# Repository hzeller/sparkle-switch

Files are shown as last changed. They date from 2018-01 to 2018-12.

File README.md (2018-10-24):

Sparkleswitch
=============

The Noisebridge Laser cutter is an expensive piece of machinery that has
some non-negligible running cost and requires some safety-training before use.

We require to authenticate with an RFID showing previous laser training
in order to switch the laser on. This project contains the relevant electronics
and software to build this switch.

We use a generic EStop/On/Off switch box ([Aliexpress][switch-box-ali], [Amazon][switch-box-amazon]) as basic user interface, coupled with an
additional [RFID reader].

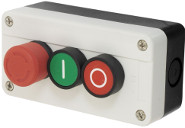
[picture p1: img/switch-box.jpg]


## Requirements

 * Have a switch that provides on/off and emergency off buttons as well
   as an RFID reader.
 * The safety relevant triggering of the emergency button **must**
   shut off power reliably by simple electromechanical means with no software
   involved to work even if the computer has issues.
   After an Emergency-Off, it is required to reset the EStop button
   (manual twisting) _and_ re-activating via RFID.
 * Have a display to show the currently active user, potentially laser
   time accounting, uplifting idle-animations etc.
 * It is common to pass the custody of the running laser cutter to the next
   user, so make it simple to switch the active user without power-cycling
   the laser.
 * Connection between Pi and emergency off button is separate, so it should
   be simple to wire up.

## Design considerations

As controlling computer, we use a Raspberry Pi: it is cheap, [can run
a LED display][rpi-rgb-matrix], and has enough additional GPIO pins to
read button state and trigger relays.

Since we need to switch line voltage with the Pi, we use a relay.
The basic switch mechanism is a simple relay circuit acting as a Set/Reset
Flip-Flop that fails safe on power loss.
Two control relays for set/reset are triggered by the Raspberry Pi; the main
switching 4-pole relay is part of the flip-flop and also switching the
mains phases for the machine.

The mains relay uses one of its poles to act as self-sustaining relay.
A momentary switch of the 'on' trigger relay will switch on the machine,
and a momentary interrupt from the 'off' trigger will switch off the machine:

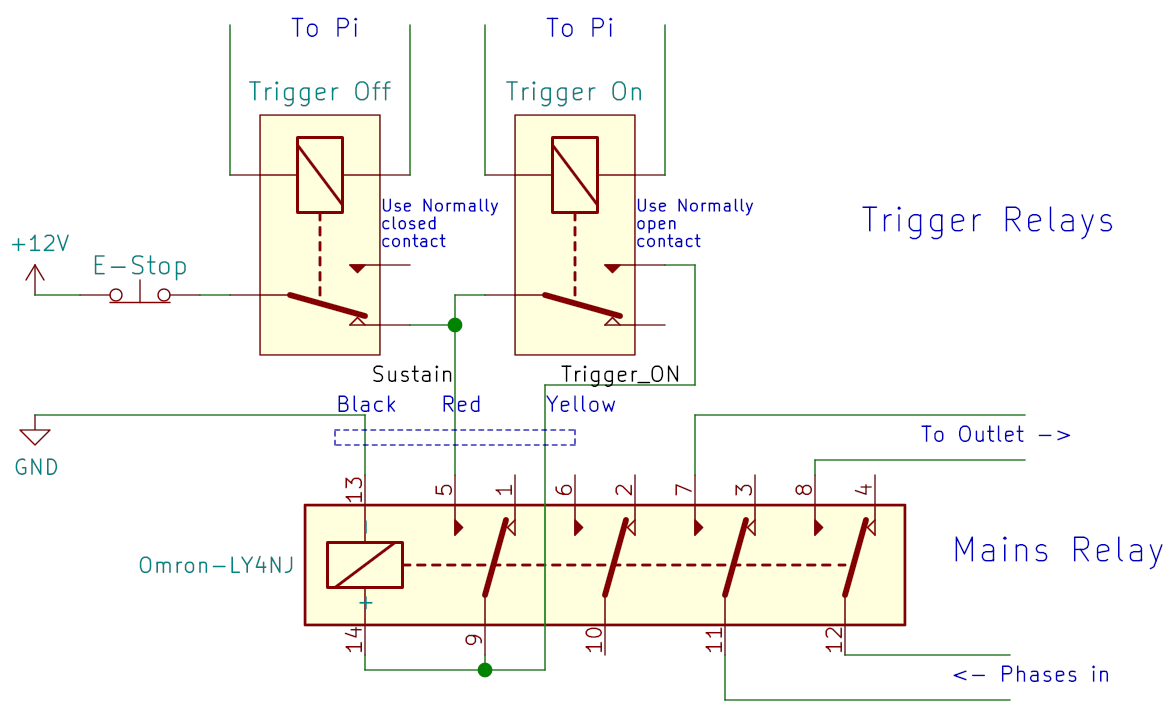
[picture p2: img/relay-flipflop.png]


The Emergency-Off button is cutting power to the relay circuit, thus acting
as master reset (thereby meeting the no-software-involved safety requirements).
Set (= switch power on) and Reset (= switch power off) are triggered by the
Raspberry Pi.

Inputs and outputs are

 * `in` **Emergency Off** button. Directly wired in the
    circuit acting as physical 'reset' for the SR-FlipFlop. Also wired to a
    GPIO as input to inform the application about the state.
 * `in` **On** button. Wired to a GPIO input as a soft-button for
    the application.
 * `in` **Off** button. Wired to a GPIO input as a soft-button for the
    application.
 * `in` a sense input to detect if the mains-relay coil voltage is on. Mostly
    for fault detection via software.
 * `out` **Trigger on** relay. Controlled by GPIO
    to trigger *set* of SR-FlipFlop.
 * `out` **Trigger off** relay. Controlled by GPIO
    to trigger *reset* of SR-FlipFlop.
 * `serial in/out` **RFID** reader (connected to UART on Pi).

Since we use the on/off buttons to interact with the application as
soft-buttons (e.g. to trigger 'pending off'), they are not physically wired
into the circuit but used as input to the computer (this is fine as they
are not in the safety critical path).

There is a little space in the switch box which will house the trigger relays
and possibly the RFID reader. The relay switching of the line voltage for the
laser cutter is mounted near the outlet for the machine, connected with three
wires (see above:`GND`, `Sustain`, `Trigger ON`) remotely from the switch box.

As trigger relays, we use off-the-shelf and [cheap][ebay-search-dual-relay]
relays.

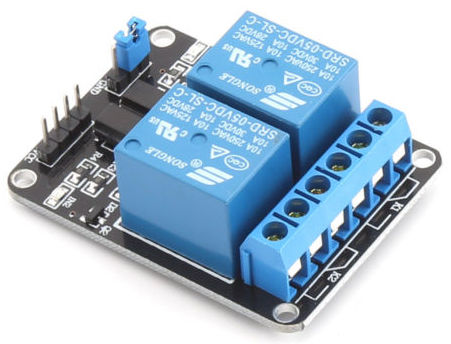
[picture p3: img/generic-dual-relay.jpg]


## State machine

The software on the Pi implements the following state machine; it uses inputs
and outputs mentioned above.
Inputs are on the transition edges; external actions triggered by the
application are represented as hexagons. Since we often have the situation
that we want to pass the running laser to the next user without having to
switch it entirely off and on again, there is a provision to change the user
while the machine is running:

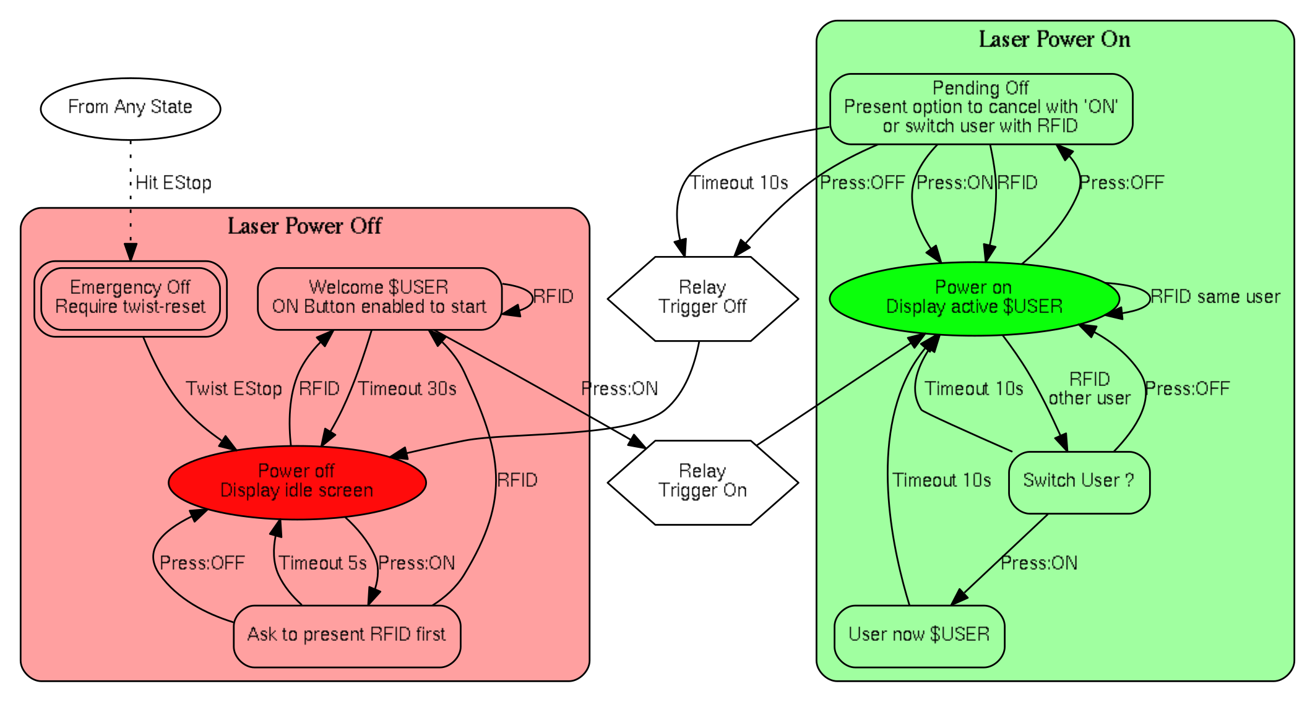
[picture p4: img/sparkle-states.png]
Sparkleswitch states


## Components

There are three physical parts to the system:

  1. RGB LED matrix screen, that has a Raspberry Pi connected to it to
     display the user interface.
  2. The switch box is separate from that and mounted under the display.
  3. The mains relay that is close to the outlet of the
     laser-cutter, and remotely controlled with a 12V control voltage.

The connection between the switch-box and the Pi is a simple flat cable with
an [IDC-12 connector] on both ends.

| Desc | Pin | Pin | Desc
|---:|:---:|:---:|:---
| +5V  | 1 | 2 | +5V (low current; for trigger relays and RFID)
| Sense EStop `in` | 3 | 4 | `in` sense relay voltage (e.g. for failure detection)
| Off-Button `in` | 5 | 6 | `out` Relay Trigger Off
| On-Button `in` | 7 | 8 | `out` Relay Trigger On
| GND  | 9 |  10 | GND
| UART RX on Pi  |  11 |  12 | UART TX on Pi (3.3V TTL)

There is a PCB on the Raspberry Pi to wire up the LED panels and provide the
connector to the switch-box, and a PCB in the switch-box as a breakout board.

### Pi Sparkle HAT

The Rasbperry Pi connects to the [Pi Sparkle HAT](./hardware/pi-hat), that
provides connections for two chains of HUB75 RGB LED matrix
(using the [rpi-rgb-matrix] project) and the
Sparkleswitch-specific IDC-12 connector to connect to the switch box.

Inputs (from switches and sense-lines all operating at 12V) are insulated with
opto couplers. The relay trigger outputs are 5V TTL
(but non-insulated as the receiving end uses opto-couplers already).

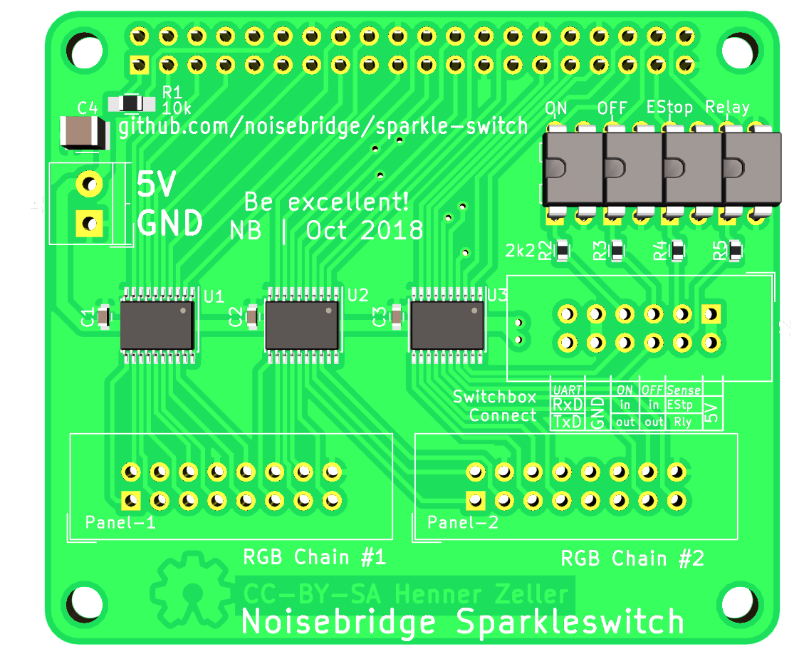
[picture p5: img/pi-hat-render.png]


### Switch Box

A [small breakout board in the switch-box](./hardware/switch-connector)
provides a way to connect the switches, the Trigger-Relays (housed inside the
switch-box) and the RFID reader (attached to switch box). It also provides a
screw terminal to wire up to the mains-relay whose wires are also terminating
in the switch box.

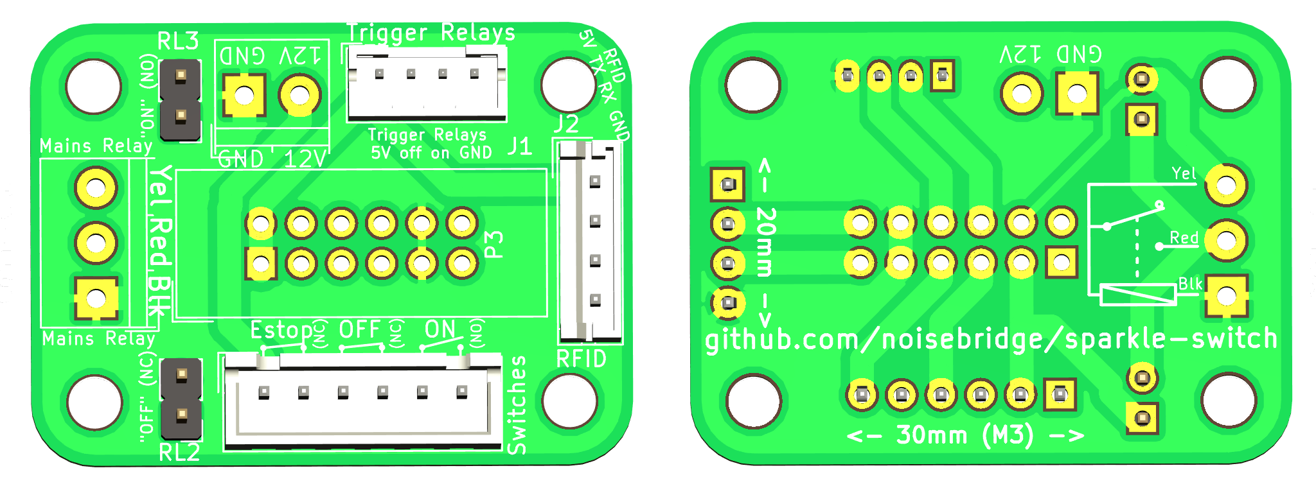
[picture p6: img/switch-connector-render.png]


[switch-box-ali]: https://www.aliexpress.com/wholesale?SearchText=NC+Emergency+Stop+Red+Green
[switch-box-amazon]: https://www.amazon.com/gp/product/B0097B4YK0
[rpi-rgb-matrix]: https://github.com/hzeller/rpi-rgb-led-matrix
[RFID reader]: https://github.com/noisebridge/rfid-access-control/tree/master/hardware/terminal
[IDC-12 Connector]: https://www.google.com/images?q=idc-12+connector
[ebay-search-dual-relay]: https://www.ebay.com/sch/i.html?_nkw=%222+channel%22+relay+arduino&_sop=15

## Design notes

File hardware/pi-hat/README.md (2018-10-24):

Pi Sparkle HAT
==============

The Sparkle HAT connects to Raspberry Pi GPIOs, does 3.3V->5V level shifting
to connect to HUB75 LED matrixes (to be controlled with the [rpi-rgb-matrix]
code), and the Sparkleswitch-specific IDC-12 connector to connect to the
switch box.

The level shifters are needed as the LED matrixes need 5V logic level. We also
use two free drivers to provide 5V TTL level for the trigger relay outputs
on the IDC-12 connector.

Inputs (from switches and sense-lines all operating at 12V) are insulated with
PC817 opto couplers. The relay trigger outputs are non-insulated as the
receiving end uses opto-couplers already.

To provide strong mechanical support, the HAT is full size with all four
mounting holes.

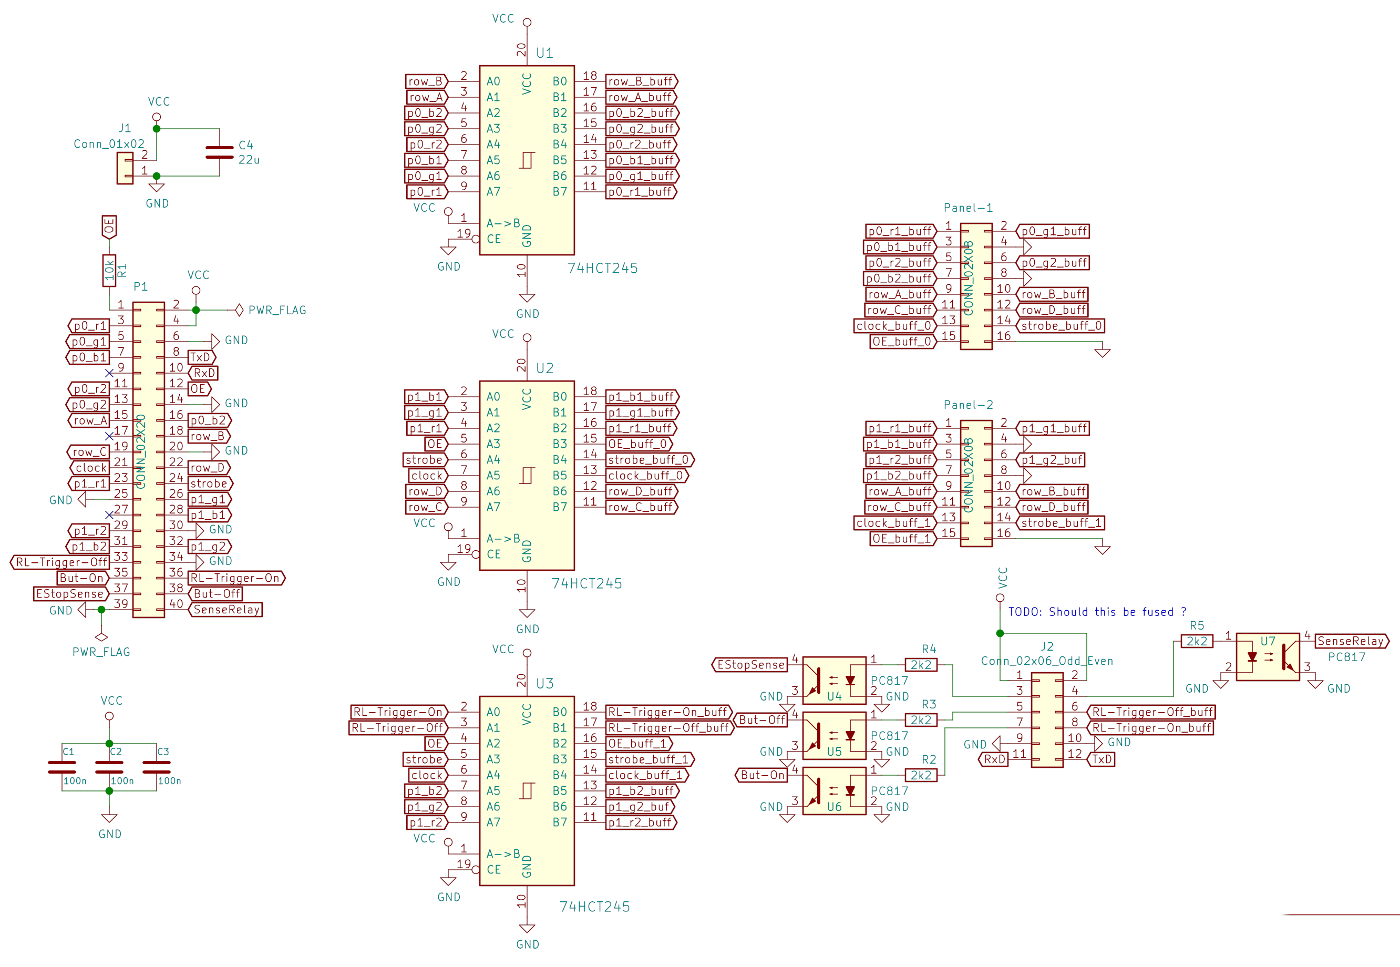
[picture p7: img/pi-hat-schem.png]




[rpi-rgb-matrix]: https://github.com/hzeller/rpi-rgb-led-matrix

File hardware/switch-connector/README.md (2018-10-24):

Switch Connector
================

The IDC-12 cable from the Raspberry Pi terminates inside the switch box.



There, it needs to connect to

   * The RFID reader via the serial interface.
   * Switches to sense which buttons are pressed (sent to Pi).
   * EStop button that is wired up as physical master-reset of the
     relay Set/Reset flip-flop. Also its state is sensed and sent to
     Pi to detect that condition in software.
   * Trigger relay inputs, controlled from the Pi.
   * The trigger relay switches, that are part of the Set/Reset flip-flop
   * And finally: the wires to the large mains relay.

To simplify that and improve maintainability, this is a small PCB inside the
switch box that provides the necessary connectors.

The IDC-12 connector has the following pinout:

| Desc | Pin | Pin | Desc
|---:|:---:|:---:|:---
| +5V  | 1 | 2 | +5V (low current; for trigger relays and RFID)
| Sense EStop `in` | 3 | 4 | `in` sense relay voltage (e.g. for failure detection)
| Off-Button `in` | 5 | 6 | `out` Relay Trigger Off
| On-Button `in` | 7 | 8 | `out` Relay Trigger On
| GND  | 9 |  10 | GND
| UART RX on Pi  |  11 |  12 | UART TX on Pi (3.3V TTL)

The connector to the On/Off/EStop switches is a 6 pos JST-XH connector,
which can be cheaply acquired pre-crimped, as they are also used as
battery charge balance connectors.

The connectors to the [RFID reader], and the input to the trigger relay are
also JST connectors. The former uses JST-XH (2.5mm pitch), the latter
JST-PH (2mm pitch) to avoid wrong wirings.

As trigger relay, simple generic dual relays are used, that are super-cheap
[on ebay][ebay-search-dual-relay]



## Schematic and Board

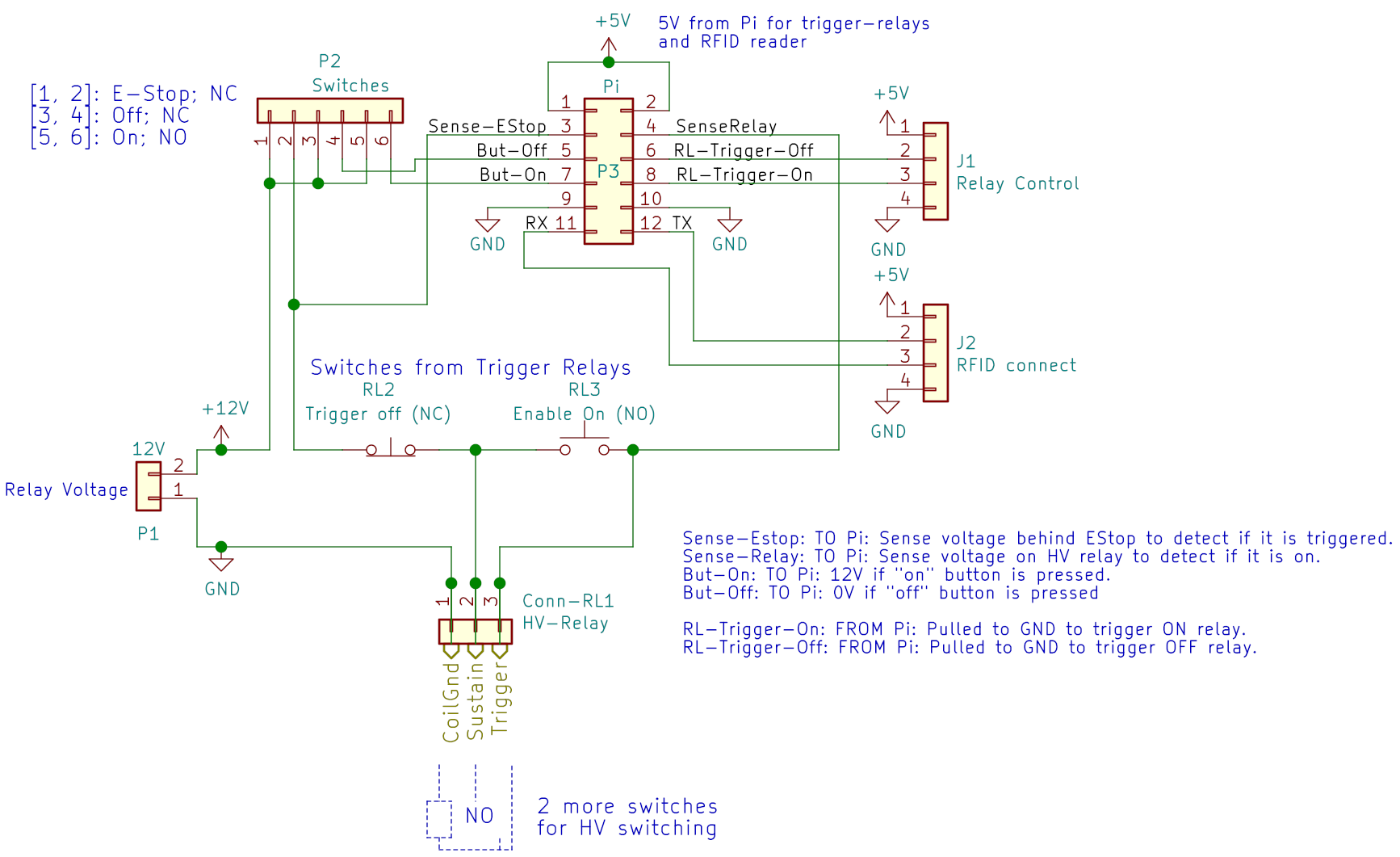
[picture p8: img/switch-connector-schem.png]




[RFID Reader]: https://github.com/noisebridge/rfid-access-control/tree/master/hardware/terminal
[ebay-search-dual-relay]: https://www.ebay.com/sch/i.html?_nkw=%222+channel%22+relay+arduino&_sop=15

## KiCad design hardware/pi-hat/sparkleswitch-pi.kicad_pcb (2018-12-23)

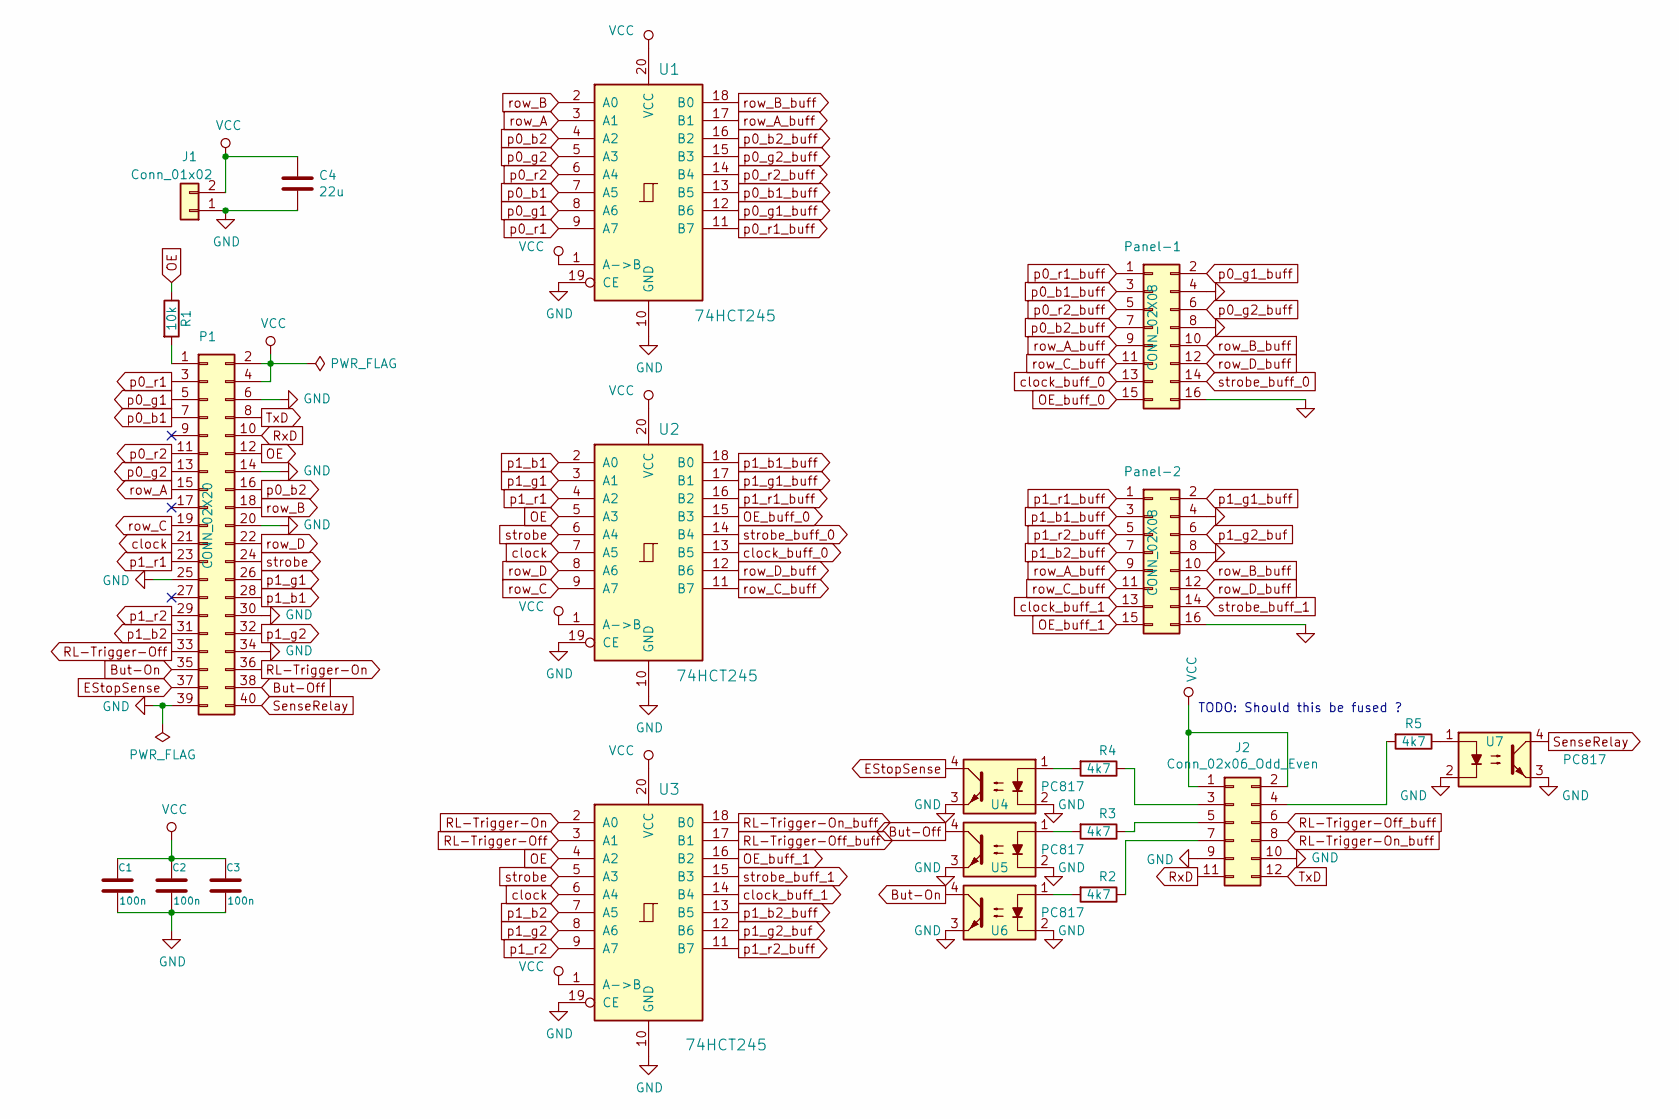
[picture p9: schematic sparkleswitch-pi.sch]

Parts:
C1, C2, C3: 100n; C_0603
C4: 22u; C_1210
J1: Conn_01x02; TerminalBlock_4UCON_19963_02x3.5mm_Straight
J2: Conn_02x06_Odd_Even; IDC-Header_2x06_Pitch2.54mm_Straight
P1: CONN_02X20; Socket_Strip_Straight_2x20_Pitch2.54mm
Panel-1, Panel-2: CONN_02X08; IDC-Header_2x08_Pitch2.54mm_Straight
R1: 10k; R_0603
R2, R3, R4, R5: 4k7; R_0603
U1, U2, U3: 74HCT245; SSOP-20_4.4x6.5mm_Pitch0.65mm
U4, U5, U6, U7: PC817; DIP-4_W7.62mm

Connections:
But-Off: P1.38, U5.4
But-On: P1.35, U6.4
EStopSense: P1.37, U4.4
GND: C1.2, C2.2, C3.2, C4.2, J1.1, J2.9, J2.10, P1.6, P1.14, P1.20, P1.25, P1.30, P1.34, P1.39, Panel-1.4, Panel-1.8, Panel-1.16, Panel-2.4, Panel-2.8, Panel-2.16, U1.10 (GND), U1.19 (CE), U2.10 (GND), U2.19 (CE), U3.10 (GND), U3.19 (CE), U4.2, U4.3, U5.2, U5.3, U6.2, U6.3, U7.2, U7.3
unnamed: J2.3, R4.1
unnamed: J2.4, R5.2
unnamed: J2.5, R3.1
unnamed: J2.7, R2.1
unnamed: P1.1, R1.2
unnamed: R2.2, U6.1
unnamed: R3.2, U5.1
unnamed: R4.2, U4.1
unnamed: R5.1, U7.1
OE: P1.12, R1.1, U2.5 (A3), U3.4 (A2)
OE_buff_0: Panel-1.15, U2.15 (B3)
OE_buff_1: Panel-2.15, U3.16 (B2)
RL-Trigger-Off: P1.33, U3.3 (A1)
RL-Trigger-Off_buff: J2.6, U3.17 (B1)
RL-Trigger-On: P1.36, U3.2 (A0)
RL-Trigger-On_buff: J2.8, U3.18 (B0)
RxD: J2.11, P1.10
SenseRelay: P1.40, U7.4
TxD: J2.12, P1.8
VCC: C1.1, C2.1, C3.1, C4.1, J1.2, J2.1, J2.2, P1.2, P1.4, U1.1 (A->B), U1.20 (VCC), U2.1 (A->B), U2.20 (VCC), U3.1 (A->B), U3.20 (VCC)
clock: P1.21, U2.7 (A5), U3.6 (A4)
clock_buff_0: Panel-1.13, U2.13 (B5)
clock_buff_1: Panel-2.13, U3.14 (B4)
p0_b1: P1.7, U1.7 (A5)
p0_b1_buff: Panel-1.3, U1.13 (B5)
p0_b2: P1.16, U1.4 (A2)
p0_b2_buff: Panel-1.7, U1.16 (B2)
p0_g1: P1.5, U1.8 (A6)
p0_g1_buff: Panel-1.2, U1.12 (B6)
p0_g2: P1.13, U1.5 (A3)
p0_g2_buff: Panel-1.6, U1.15 (B3)
p0_r1: P1.3, U1.9 (A7)
p0_r1_buff: Panel-1.1, U1.11 (B7)
p0_r2: P1.11, U1.6 (A4)
p0_r2_buff: Panel-1.5, U1.14 (B4)
p1_b1: P1.28, U2.2 (A0)
p1_b1_buff: Panel-2.3, U2.18 (B0)
p1_b2: P1.31, U3.7 (A5)
p1_b2_buff: Panel-2.7, U3.13 (B5)
p1_g1: P1.26, U2.3 (A1)
p1_g1_buff: Panel-2.2, U2.17 (B1)
p1_g2: P1.32, U3.8 (A6)
p1_g2_buf: Panel-2.6, U3.12 (B6)
p1_r1: P1.23, U2.4 (A2)
p1_r1_buff: Panel-2.1, U2.16 (B2)
p1_r2: P1.29, U3.9 (A7)
p1_r2_buff: Panel-2.5, U3.11 (B7)
row_A: P1.15, U1.3 (A1)
row_A_buff: Panel-1.9, Panel-2.9, U1.17 (B1)
row_B: P1.18, U1.2 (A0)
row_B_buff: Panel-1.10, Panel-2.10, U1.18 (B0)
row_C: P1.19, U2.9 (A7)
row_C_buff: Panel-1.11, Panel-2.11, U2.11 (B7)
row_D: P1.22, U2.8 (A6)
row_D_buff: Panel-1.12, Panel-2.12, U2.12 (B6)
strobe: P1.24, U2.6 (A4), U3.5 (A3)
strobe_buff_0: Panel-1.14, U2.14 (B4)
strobe_buff_1: Panel-2.14, U3.15 (B3)

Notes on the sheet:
TODO: Should this be fused ?

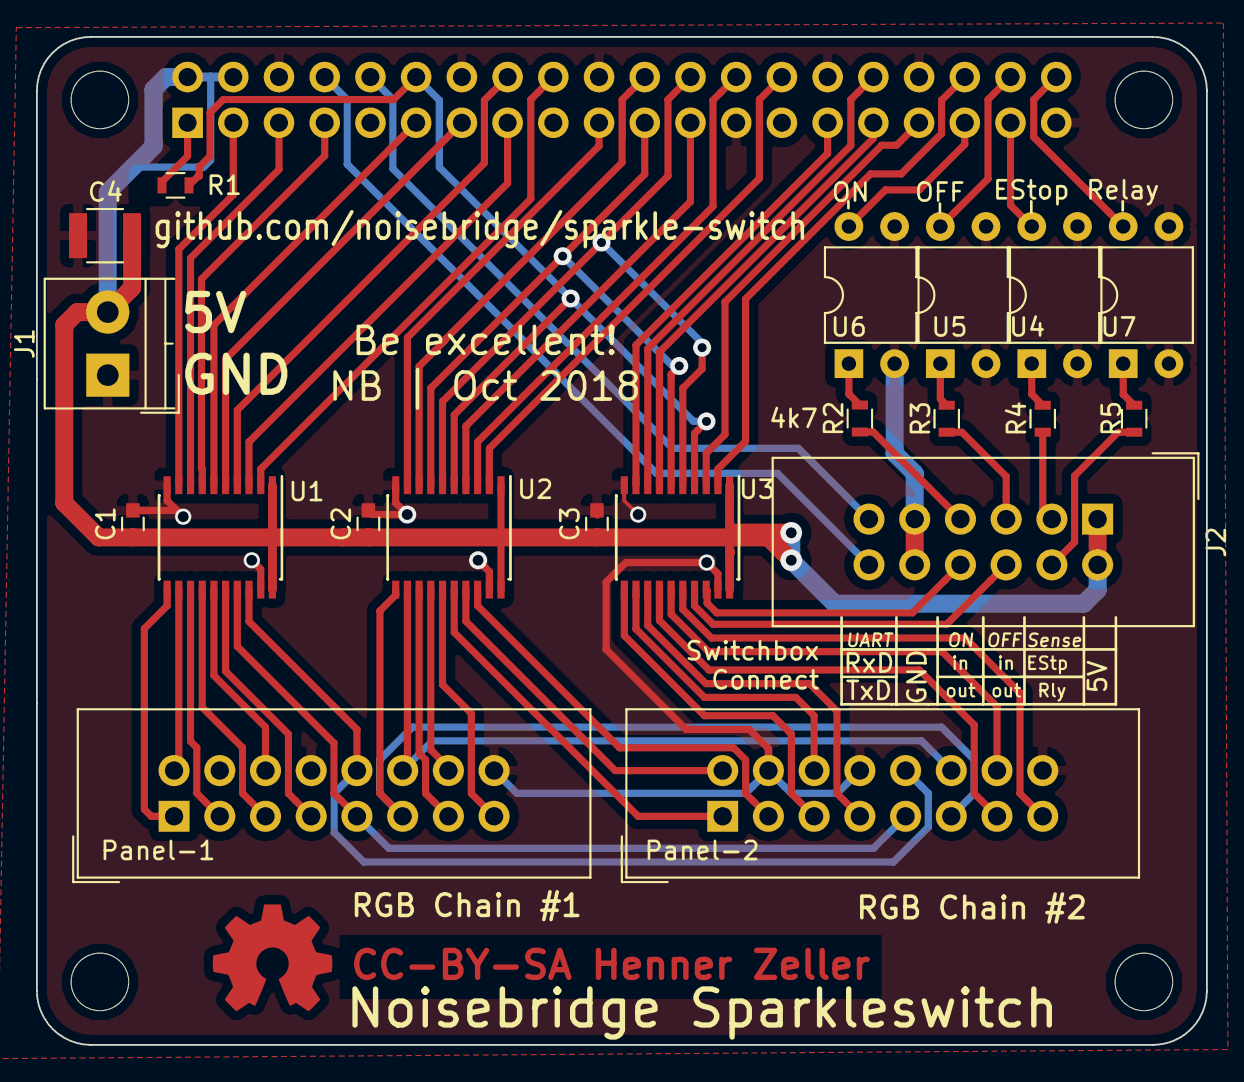
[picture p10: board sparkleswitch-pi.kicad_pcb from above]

Board: 2 copper layers, 65.0 x 56.0 mm, 21 parts (1 on the bottom side), 62 nets.

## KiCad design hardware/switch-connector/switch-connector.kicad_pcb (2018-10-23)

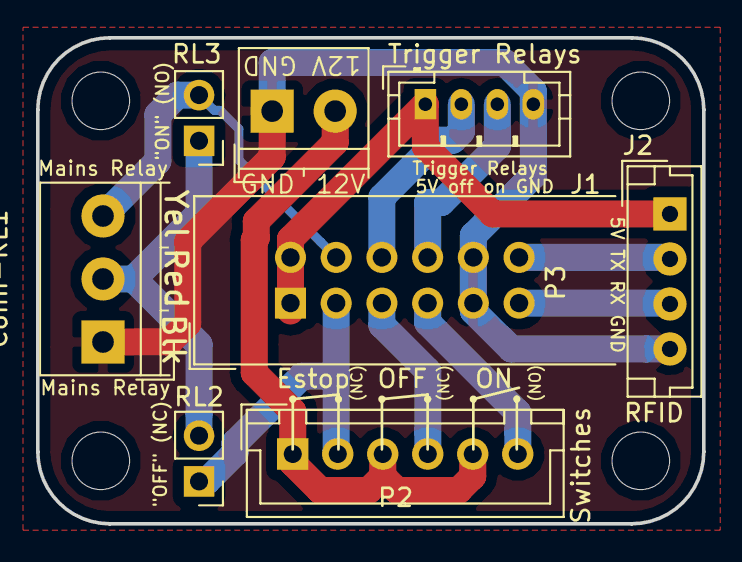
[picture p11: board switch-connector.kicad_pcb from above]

Board: 2 copper layers, 37.0 x 27.0 mm, 8 parts (0 on the bottom side), 12 nets.

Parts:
Conn-RL1: HV-Relay; TerminalBlock_4UCON_19963_03x3.5mm_Straight
J1: Relay Control; JST_PH_B4B-PH-K_04x2.00mm_Straight
J2: RFID connect; JST_EH_B04B-EH-A_04x2.50mm_Straight
P1: 12V; TerminalBlock_4UCON_19963_02x3.5mm_Straight
P2: Switches; JST_XH_B06B-XH-A_06x2.50mm_Straight
P3: Pi; IDC-Header_2x06_Pitch2.54mm_Straight
RL2: Trigger off (NC); Pin_Header_Straight_1x02_Pitch2.54mm
RL3: Enable On (NO); Pin_Header_Straight_1x02_Pitch2.54mm

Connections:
+5V: J1.1, J2.1, P3.1, P3.2
+12V: P1.2, P2.1, P2.3, P2.5
/Sustain: Conn-RL1.2, RL2.2, RL3.1
/Trigger: Conn-RL1.3, P3.4, RL3.2
/switch-box/But-Off: P2.4, P3.5
/switch-box/But-On: P2.6, P3.7
/switch-box/RL-Trigger-Off: J1.2, P3.6
/switch-box/RL-Trigger-On: J1.3, P3.8
/switch-box/RX: J2.3, P3.11
/switch-box/Sense-EStop: P2.2, P3.3, RL2.1
/switch-box/TX: J2.2, P3.12
GND: Conn-RL1.1, J1.4, J2.4, P1.1, P3.9, P3.10

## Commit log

2016-08-27 o Initial set of files
    [panel-mount-large.dxf]
2016-08-27 o Fix sizes.
    [panel-mount-large.dxf]
2017-02-20 o Submit switch connector.
    [panel-mount-large.dxf, switch-connector.kicad_pcb, switch-connector.sch]
2017-02-20 o make hierarchical sheet.
    [switch-box.sch, switch-connector.sch]
2017-02-20 New local parts lib with quad-pole relay.
2017-02-20 o Update board with new connectors.
    [switch-box.sch, switch-connector.kicad_pcb]
2017-02-21 o tweaks.
    [switch-connector.kicad_pcb]
2017-02-21 o Add relay to the toplevel schematic
    [switch-box.sch, switch-connector.sch]
2017-02-21 o clarifications in schematic
    [switch-box.sch, switch-connector.sch]
2017-12-29 Upgrade to new eeschema lib.
    [switch-box.sch, switch-connector.sch]
2017-12-29 A little more silkscreen to ease assembly.
    Also:
    o enough space for actual connectors for switches and sense outputs
    o have inputs for every single switch ('eStop' and 'off' were sharing one)
    [switch-box.sch, switch-connector.kicad_pcb, switch-connector.sch]
2017-12-29 Rounded corners.
    [switch-connector.kicad_pcb]
2017-12-29 Add screw terminal for 12V
    [switch-box.sch, switch-connector.kicad_pcb]
2018-01-01 Add a generic relay for illustration schematics.
2018-01-06 Some tweaking (but about to be changed for refined design)
    [switch-connector.kicad_pcb]
2018-01-06 Update schematic to refined design.
    (PCB still needs to be adapted)
    [switch-box.sch, switch-connector.sch]
2018-01-06 Add stub README for switch-connector.
2018-01-06 Use IDC-12 for lower impedance 5V/GND connection.
    The flat cable might be a meter or so long, the 5V relays might need
    some current and the strands are flimsy.
    Also, better separation of the 12V-ish logic and the RX/TX wiring.
    [switch-box.sch]
2018-01-06 Exclude mouse cursor in schematic screenshot.
2018-01-06 Fix typo in README. Wire a signal directly (instead of labels) where possible.
    [switch-box.sch]
2018-10-23 First version of the PCB using the IDC connector.
    [switch-box.sch, switch-connector.kicad_pcb, switch-connector.sch]
2018-10-23 Update Schematic image in README; smallish tweaks in PCB.
    [switch-connector.kicad_pcb]
2018-10-23 Update README with clarifications; add switch-box PCB rendering.
    [switch-connector.kicad_pcb]
2018-10-23 Show front and back of box-switch pcb.
2018-10-23 Start hat for Pi to control LED panels and switch box.
    [sparkleswitch-pi.sch, switch-connector.kicad_pcb]
2018-10-24 First wiring up with somewhat minimized via count.
    This required to rewire GPIOs a little, but since this is a specific
    set-up anyway.
    [sparkleswitch-pi.kicad_pcb, sparkleswitch-pi.sch]
2018-10-24 First version with all connections.
    [sparkleswitch-pi.kicad_pcb]
2018-10-24 Make traces thicker as we have the space.
    o Increase size of traces from 0.25mm to 0.4mm as space is
    not that constricted (right now only the afferent traces).
    [sparkleswitch-pi.kicad_pcb, sparkleswitch-pi.sch]
2018-10-24 Thicker efferent traces.
    [sparkleswitch-pi.kicad_pcb]
2018-10-24 More space between Led Matrix HUB75 IDC connectors.
    .. to make sure they don't physically interfere.
    [sparkleswitch-pi.kicad_pcb]
2018-10-24 Center middle '245
    [sparkleswitch-pi.kicad_pcb, sparkleswitch-pi.sch]
2018-10-24 Add helpful silkscreen markings.
    [sparkleswitch-pi.kicad_pcb, sparkleswitch-pi.sch]
2018-10-24 Update documentation.
    [sparkleswitch-pi.kicad_pcb]
2018-10-25 More relay flip-flop illustration tweaks.
2018-12-23 Use 4.7k for OptoCoupler LEDs; OE-Pullup 0805 -> 0603
    [sparkleswitch-pi.kicad_pcb, sparkleswitch-pi.sch]

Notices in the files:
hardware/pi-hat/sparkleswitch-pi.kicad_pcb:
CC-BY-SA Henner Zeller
